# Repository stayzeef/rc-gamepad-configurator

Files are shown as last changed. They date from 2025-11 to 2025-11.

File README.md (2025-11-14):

# RC Gamepad Dongle

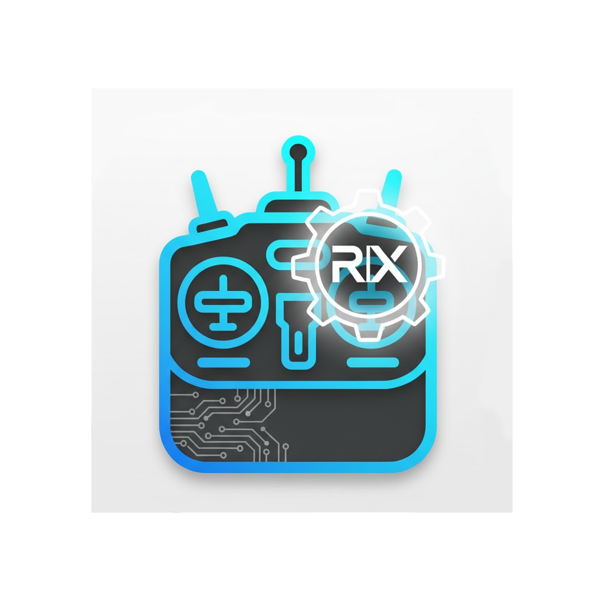
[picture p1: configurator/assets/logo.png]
RC Gamepad Dongle


Turn your RC receiver into a USB game controller. This Arduino-based adapter converts RC signals (IBUS, PPM, SBUS, and more) into standard USB HID joystick inputs that work with Windows, Linux, Mac, Android, and any device that recognizes USB game controllers.

## What Does It Do?

The RC Gamepad Dongle bridges the gap between your RC receiver and your computer. Whether you're using it for flight simulators, robot control, or custom gaming setups, this dongle translates your RC radio signals into joystick inputs that any software can understand.

The project includes Arduino firmware for the dongle itself and a desktop configurator app that makes setup straightforward.

## Key Features

- **Full HID Support**: 6 axes, 32 buttons, and 2 hat switches
- **Multiple RC Protocols**: IBUS, PPM, SBUS, CRSF, DSMX, DSM2, FPORT
- **Easy Configuration**: Map any RC channel to any joystick control
- **Simple Hardware**: Based on the affordable Arduino Pro Micro
- **Cross-Platform**: Works on Windows and Linux

## Hardware You'll Need

### Parts List

- **Arduino Pro Micro** (16MHz/5V version)
- **10kΩ resistor** (for the mode switch)
- **Toggle switch** (to switch between config and joystick modes)
- **WS2812 LED** (optional, gives you visual status feedback)

## Building Your Dongle

You can build this project two ways: you can solder a frankenstein or build a custom PCB

### Option 1: Frankenstein Build
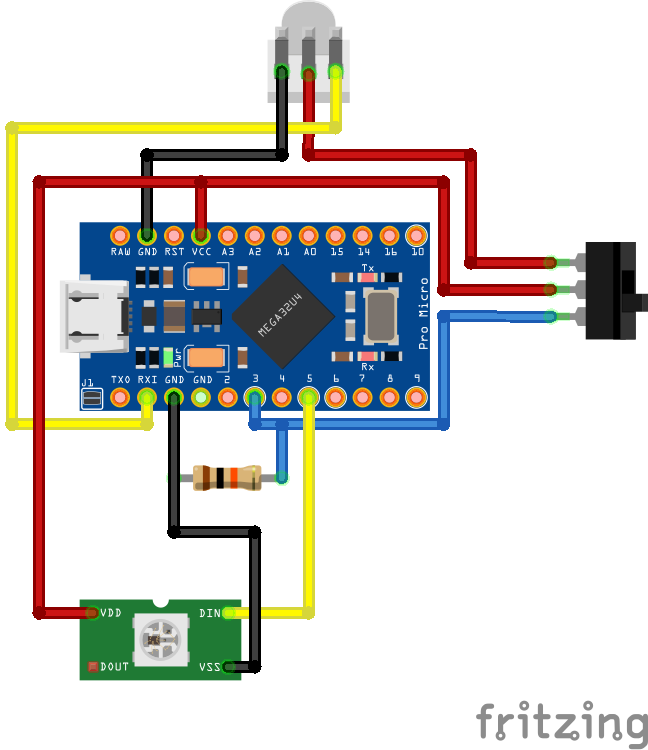
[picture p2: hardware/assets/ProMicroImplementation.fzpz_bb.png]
Breadboard Wiring


**Pin Connections:**
- **Pin 0 (RX)**: Connect your RC receiver signal here
- **Pin 3**: Mode switch (HIGH for config mode, LOW for joystick mode)
    - Connect 10kΩ resistor to ground
- **Pin 5**: Optional WS2812 LED for status indication
- **GND**: Ground connection
- **VCC**: 5V power

### Option 2: Custom PCB

If you want a cleaner build, there's a custom PCB design with all the features built in, including a hardware inverter for SBUS receivers. All the files you need are in `hardware/PCB/`:
- **[Gerber files](hardware/PCB/Gerber_RC-Gamepad-Dongle_V0.1_2025-11-13.zip)**: Ready to send to your PCB manufacturer
- **[Schematic](hardware/PCB/SCH_RC-Gamepad-Dongle%20V0.1_2025-11-13.pdf)**: Full circuit diagram
- **[BOM](hardware/PCB/BOM_RC-Gamepad-Dongle%20V0.1_RC-Gamepad-Dongle%20V0.1_2025-11-13.xlsx)**: Complete parts list with quantities

## Getting Started

### Step 1: Flash the Firmware

First, upload the firmware to your Arduino Pro Micro:

```bash
cd hardware/
pio run --target upload
```

### Step 2: Run the Configurator

**Windows:** Just run the `.exe` file

**Linux:**
```bash
chmod +x RC_Gamepad_Configurator-x86_64.AppImage
./RC_Gamepad_Configurator-x86_64.AppImage
```

**Or run from source:**
```bash
cd configurator
python -m venv .venv
source .venv/bin/activate  # Windows: .venv\Scripts\activate
pip install -r requirements.txt
python src/rc-gamepad-dongle.py
```

### Step 3: Configure Your Channels

1. Flip your mode switch to config mode (pin 3 HIGH)
2. Plug the dongle into your computer via USB
3. Open the configurator app
4. Pick your RC protocol from the dropdown
5. Map your RC channels to the joystick controls you want
6. Click save to write the configuration to the dongle
7. Flip the mode switch back to joystick mode (pin 3 LOW)

That's it! Your dongle is now ready to use as a game controller.

## Supported RC Protocols

| Protocol | Status | Baud Rate | Notes |
|---|---|---|---|
| IBUS | ✅ Tested | 115200 | Works great with FlySky receivers |
| PPM | ✅ Tested | N/A | Standard 8-channel PPM |
| SBUS | ⚠️ Untested | 100000 | Needs hardware inverter (included in PCB) |
| CRSF | ⚠️ Untested | 420000 | TBS Crossfire protocol |
| DSMX | ⚠️ Untested | 115200 | Spektrum DSMX receivers |
| DSM2 | ⚠️ Untested | 115200 | Spektrum DSM2 receivers |
| FPORT | ⚠️ Untested | 115200 | FrSky F.Port protocol |

**Note:** Protocols marked as untested are implemented according to their specifications but haven't been verified with actual hardware yet. If you test one of these, please let us know how it goes!

## Building From Source

### Building the Configurator

**Windows:**
```powershell
.\configurator\scripts\windows\build-exe.ps1
```

**Linux:**
```bash
./configurator/scripts/linux/build-appimage.sh
```

### Building the Firmware

```bash
cd hardware/
pio run                    # Compile the firmware
pio run --target upload    # Upload to your Arduino
pio device monitor         # Monitor serial output
```
## License

This project is released under the MIT License - see [LICENSE](LICENSE) for details.

## Contributing

Want to help improve this project? Pull requests are welcome! I'd especially appreciate help testing the protocols that haven't been verified yet (SBUS, CRSF, DSM, and FPORT). If you have one of these receivers, give it a try and let us know how it works.

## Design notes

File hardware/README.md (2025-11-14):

# RC Gamepad Dongle Firmware

Arduino firmware for the RC Gamepad Configurator project.

## Hardware Assembly

### Breadboard Build
**Components:**
- Arduino Pro Micro (16MHz/5V)
- 10kΩ resistor (pullup for mode switch)
- Toggle switch (mode selection)
- WS2812 LED (optional, status indication)

**Wiring Diagram:**
See `assets/ProMicroImplementation.fzpz_bb.png` for complete Fritzing diagram.

### Custom PCB
**Professional PCB available:**
- Gerber files: `PCB/Gerber_RC-Gamepad-Dongle_V0.1_2025-11-13.zip`
- Schematic: `PCB/SCH_RC-Gamepad-Dongle V0.1_2025-11-13.pdf` 
- BOM: `PCB/BOM_RC-Gamepad-Dongle V0.1_RC-Gamepad-Dongle V0.1_2025-11-13.xlsx`
- Includes hardware SBUS inverter

## Pin Configuration

```
Pin 3  - Mode Select (HIGH=Config, LOW=Joystick)
Pin 5  - WS2812 LED Data (optional)
Pin 0  - RX (RC Receiver Data Input) 
Pin 1  - TX (Not used)
USB    - Configuration & HID output
```

## Quick Start

```bash
cd hardware/
pio run --target upload
```

## Protocol Support

| Protocol | Status | Baud Rate | Testing |
|---|---|---|---|
| IBUS | ✅ Stable | 115200 | ✅ Tested |
| PPM | ✅ Stable | N/A | ✅ Tested |
| CRSF | ⚠️ Implemented | 420000 | ⚠️ Untested |
| SBUS | ⚠️ Implemented | 100000 | ⚠️ Untested |
| DSMX/DSM2| ⚠️ Implemented | 115200 | ⚠️ Untested |
| FPORT | ⚠️ Implemented | 115200 | ⚠️ Untested |

**Note**: Only IBUS and PPM have been tested due to hardware availability.

## Supported Controls

### Joystick Axes
- **X, Y, Z Axes**: Standard 3D movement controls
- **Rx, Ry, Rz Axes**: Rotational controls around X, Y, Z axes

### Specialized Controls  
- **Rudder**: Directional control (typically yaw)
- **Throttle**: Power/speed control
- **Accelerator**: Forward motion control
- **Brake**: Stopping/reverse control  
- **Steering**: Left/right directional control

### Digital Controls
- **32 Buttons**: Individual on/off switches
- **2 Hat Switches**: 8-direction digital controls for menus/navigation

All controls can be mapped to any RC channel (1-16) or disabled.

## Build Requirements

- [PlatformIO](https://platformio.org/)
- Arduino Pro Micro or compatible ATmega32U4 board

## Configuration

Use the GUI configurator application in the parent directory to configure the firmware via serial interface.

## License

MIT License - see main project for details.# Hardware Documentation

## Build Options

### Option 1: Breadboard Build (Beginner-Friendly)

**Required Components:**
- Arduino Pro Micro (16MHz/5V, SparkFun compatible)
- 10kΩ resistor (for mode select pullup)
- Toggle switch (SPDT recommended)
- WS2812 LED (optional, for status indication)
- Breadboard and jumper wires

**Assembly Instructions:**
1. Follow the Fritzing diagram: `hardware/assets/ProMicroImplementation.fzpz_bb.png`
2. Connect the toggle switch to Pin 3 with 10kΩ pullup resistor
3. Connect WS2812 LED data pin to Pin 5 (optional)
4. Connect RC receiver data to Pin 0 (RX)
5. Ensure proper power connections (VCC/GND)

**Wiring Details:**
```
Arduino Pro Micro Connections:
├── Pin 3: Mode Switch + 10kΩ pullup to VCC
├── Pin 5: WS2812 LED Data In (optional)
├── Pin 0: RC Receiver Data (RX)
├── VCC: +5V power
└── GND: Ground reference
```

### Option 2: Custom PCB (Professional)

**PCB Design Files (in `hardware/PCB/`):**
- `Gerber_RC-Gamepad-Dongle_V0.1_2025-11-13.zip` - Manufacturing files
- `SCH_RC-Gamepad-Dongle V0.1_2025-11-13.pdf` - Schematic diagram
- `BOM_RC-Gamepad-Dongle V0.1_RC-Gamepad-Dongle V0.1_2025-11-13.xlsx` - Bill of materials
- `DXF_RC-Gamepad-Dongle V0.1_2025-11-13_AutoCAD2007.dxf` - Mechanical drawings

**PCB Features:**
- Integrated Arduino Pro Micro footprint
- Hardware SBUS signal inverter
- Professional connectors for RC inputs
- Dedicated IBUS and SBUS ports
- Status LED integration
- Compact form factor

**Manufacturing:**
1. Upload Gerber files to PCB manufacturer (JLCPCB, PCBWay, etc.)
2. Use included BOM for component sourcing
3. Assembly can be done manually or with PCBA service

## RC Protocol Connections

### Tested Protocols
| Protocol | Connection | Hardware Notes |
|---|---|---|
| **IBUS** | Pin 0 (RX) direct | Standard 3.3V/5V logic levels |
| **PPM** | Pin 0 (RX) direct | Digital pulse train |

### Implemented Protocols (Untested)
| Protocol | Connection | Hardware Notes |
|---|---|---|
| **SBUS** | PCB SBUS port | Requires hardware inverter (included in PCB) |
| **CRSF** | Pin 0 (RX) direct | 3.3V logic, may need level shifting |
| **DSMX/DSM2** | Pin 0 (RX) direct | Standard logic levels |
| **FPORT** | Pin 0 (RX) direct | Standard logic levels |

⚠️ **Important**: Only connect ONE receiver at a time to prevent conflicts!

## Status LED Indicators

The WS2812 LED provides visual feedback:

| Color | Pattern | Meaning |
|---|---|---|
| **Blue** | Solid | Configuration mode active |
| **Green** | Solid | Joystick mode, receiving data |
| **Dim Green** | Solid | Joystick mode, no data |
| **Red** | Flash | Error condition |
| **Yellow** | Flash | EEPROM write operation |

## Power Requirements

- **Supply Voltage**: 5V via USB or VIN pin
- **Current Draw**: 
  - Base: ~50mA (Arduino + LED)
  - Peak: ~80mA (during USB enumeration)
- **Power Source**: USB port provides sufficient power

## Mechanical Specifications

- **PCB Dimensions**: See DXF file for exact measurements
- **Connector Types**: Standard RC servo connectors
- **Mounting**: Compatible with standard RC electronics mounting

## Troubleshooting

### Hardware Issues
- **No LED**: Check WS2812 wiring and power
- **No USB recognition**: Verify Arduino Pro Micro connections
- **No RC data**: Check receiver binding and connections

### Connection Issues  
- **SBUS not working**: Ensure hardware inverter is present (PCB only)
- **Multiple protocols**: Only connect one receiver type at a time
- **Loose connections**: Use proper connectors or solder joints

## Files Reference

### Fritzing Files (`hardware/assets/`)
- `ProMicroImplementation.fzpz.fzz` - Editable Fritzing project
- `ProMicroImplementation.fzpz_bb.png` - Breadboard view
- `ProMicroImplementation2.fzpz_bb.png` - Alternative view

### PCB Files (`hardware/PCB/`)
- Gerber files for manufacturing
- Complete schematic documentation
- Bill of materials with part numbers
- Mechanical drawings for enclosure design

This hardware documentation supports both beginner breadboard builds and professional PCB implementations.

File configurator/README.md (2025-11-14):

# RC Gamepad Dongle Configurator

Desktop application for configuring the RC Gamepad Dongle. Supports multiple RC protocols including AETR, TAER, and SBUS.

## Features

- Configure RC protocol mappings
- Multiple protocol support (AETR, TAER, SBUS, etc.)
- Serial communication with dongle
- Save/Load configurations
- Cross-platform (Windows & Linux)

## Building

### Windows
```powershell
.\scripts\windows\build-exe.ps1
```
Output: `src\dist\rc-gamepad-dongle.exe`

### Linux
```bash
./scripts/linux/build-appimage.sh
```
Output: `build/RC_Gamepad_Dongle-x86_64.AppImage`

## Development

### Requirements
- Python 3.8+
- PySide6
- PyInstaller
- Pillow

### Install Dependencies
```bash
pip install -r requirements.txt
```

### Run from Source
```bash
cd src
python rc-gamepad-dongle.py
```

## Documentation

See [scripts/README.md](scripts/README.md) for detailed build instructions.

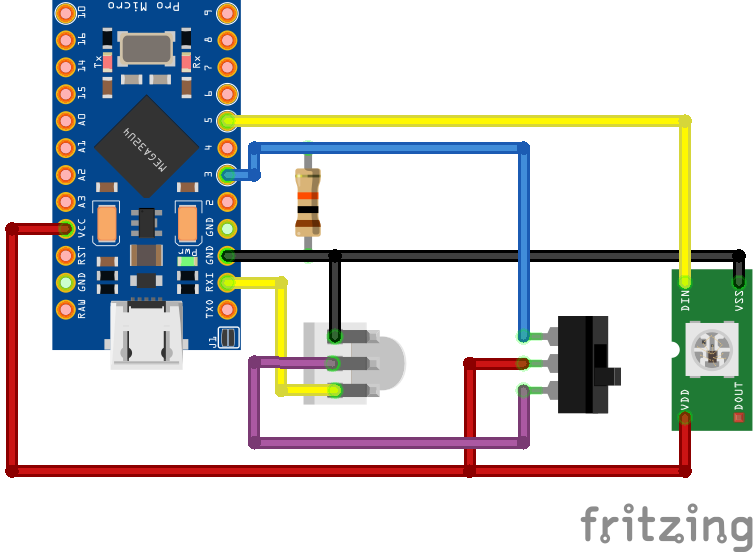
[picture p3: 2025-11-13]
hardware/assets/ProMicroImplementation2.fzpz_bb.png

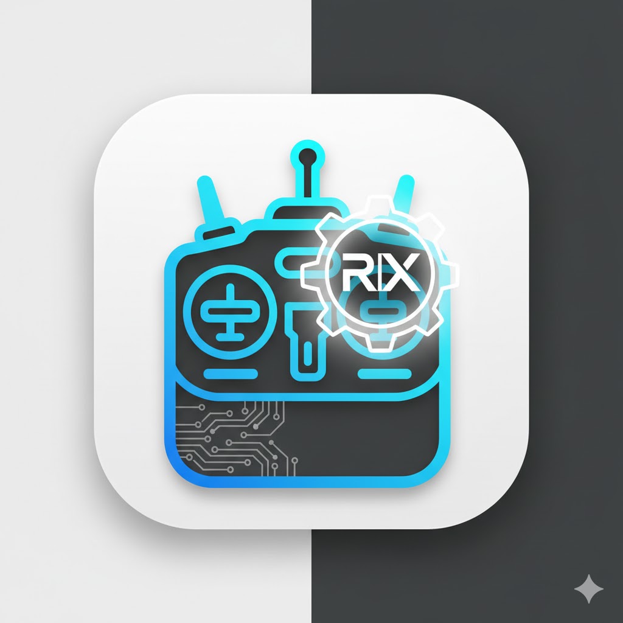
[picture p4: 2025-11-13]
configurator/assets/original.jpg

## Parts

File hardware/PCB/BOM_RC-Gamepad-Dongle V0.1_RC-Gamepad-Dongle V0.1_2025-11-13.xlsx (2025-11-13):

No. | Quantity | Comment | Designator | Footprint | Value | Manufacturer Part | Manufacturer | Supplier Part | Supplier
1 | 2 | 22pF | C1,C2 | C0603 | 22pF | CC0603JRNPO9BN220 | YAGEO(国巨) | C105620 | LCSC
2 | 3 | 100nF | C3,C5,C8 | C0603 | 100nF | CGA0603X7R104K500JT | HRE(芯声) | C6119867 | LCSC
3 | 3 | 1uF | C4,C6,C7 | C0402 | 1uF | CL05A105KP5NNNC | SAMSUNG(三星) | C14445 | LCSC
4 | 1 | SMD0805B050TF | F1 | F0805 |  | SMD0805B050TF | Brightking(君耀电子) | C269104 | LCSC
5 | 2 | SM03B-SRSS-TB(LF)(SN) | iBus,sBus | CONN-SMD_SM03B-SRSS-TB-LF-SN-P |  | SM03B-SRSS-TB(LF)(SN) | JST | C160403 | LCSC
6 | 1 | WS2812B-B/T | Mode | LED-SMD_4P-L5.0-W5.0-TL_WS2812B-B |  | WS2812B-B/T | worldsemi | C2761795 | LCSC
7 | 3 | XL-1608UYC-06 | PWR,RX,TX | LED0603-RD-YELLOW |  | XL-1608UYC-06 | XINGLIGHT(成兴光) | C965802 | LCSC
8 | 1 | 2N7002K-7 | Q1 | SOT-23_L2.9-W1.3-P1.90-LS2.4-BR |  | 2N7002K-7 | DIODES(美台) | C85047 | LCSC
9 | 2 | 22Ω | R1,R2 | R0603 | 22Ω | 0603WAF220JT5E | UNI-ROYAL(厚声) | C23345 | LCSC
10 | 5 | 10kΩ | R3,R6,R7,R8,R9 | R0603 | 10kΩ | FRC0603J103 TS | FOJAN(富捷) | C2930027 | LCSC
11 | 4 | 330Ω | R4,R5,R10,R11 | R0402 | 330Ω | FRC0402J331 TS | FOJAN(富捷) | C2906929 | LCSC
12 | 1 | SK12D07VG5 | SW1 | SW-TH_SK12D07VG5-1 |  | SK12D07VG5 | SHOU HAN(首韩) | C431548 | LCSC
13 | 1 | ATMEGA32U4-AU | U1 | QFP-44_L10.0-W10.0-P0.80-LS13.2-BL |  | ATMEGA32U4-AU | MICROCHIP(美国微芯) | C44854 | LCSC
14 | 1 | AM90 | USB1 | USB-AM-TH_AM90 |  | AM90 | SHOU HAN(首韩) | C404965 | LCSC
15 | 1 | 16MHz | X1 | OSC-SMD_4P-L5.0-W3.2-BL | 16MHz | XVHCELNANF-16MHZ | TAITIEN(泰艺电子) | C242216 | LCSC

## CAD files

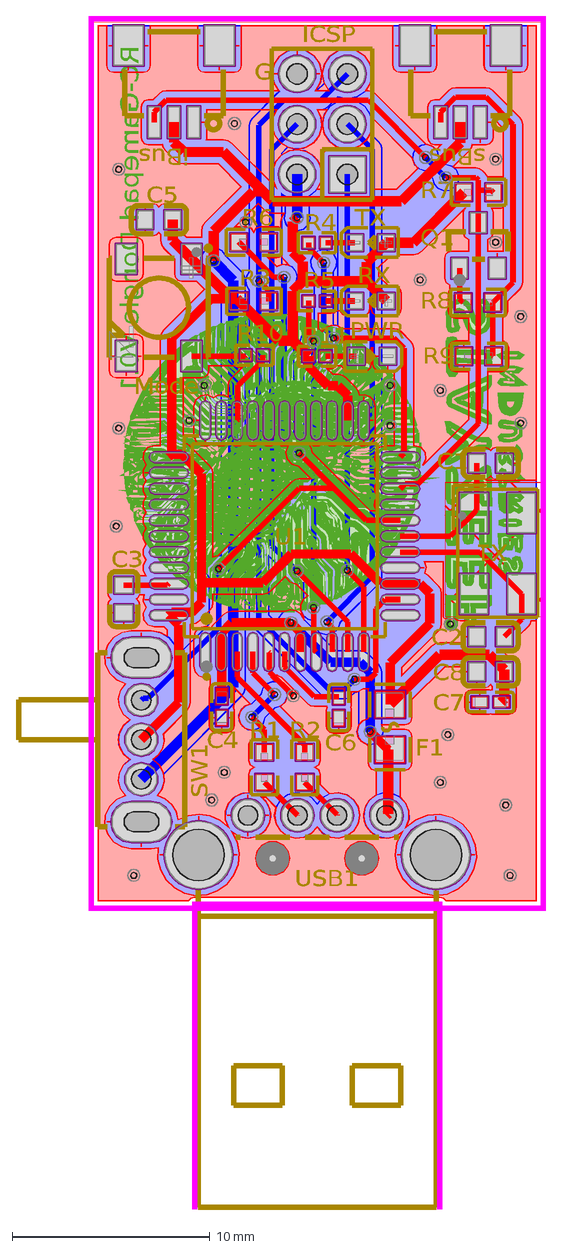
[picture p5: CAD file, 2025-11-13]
hardware/PCB/DXF_RC-Gamepad-Dongle V0.1_2025-11-13_AutoCAD2007.dxf
RC-Gamepad-Dongle V0.1
G
C1
C2
C3
C4
C5
C6
C7
C8
F1
iBus
Mode
PWR
Q1
R1
R2
R3
R4
R5
R6
R7
R8
R9
R10
R11
RX
sBus
SW1
TX
U1
USB1
X1
ICSP

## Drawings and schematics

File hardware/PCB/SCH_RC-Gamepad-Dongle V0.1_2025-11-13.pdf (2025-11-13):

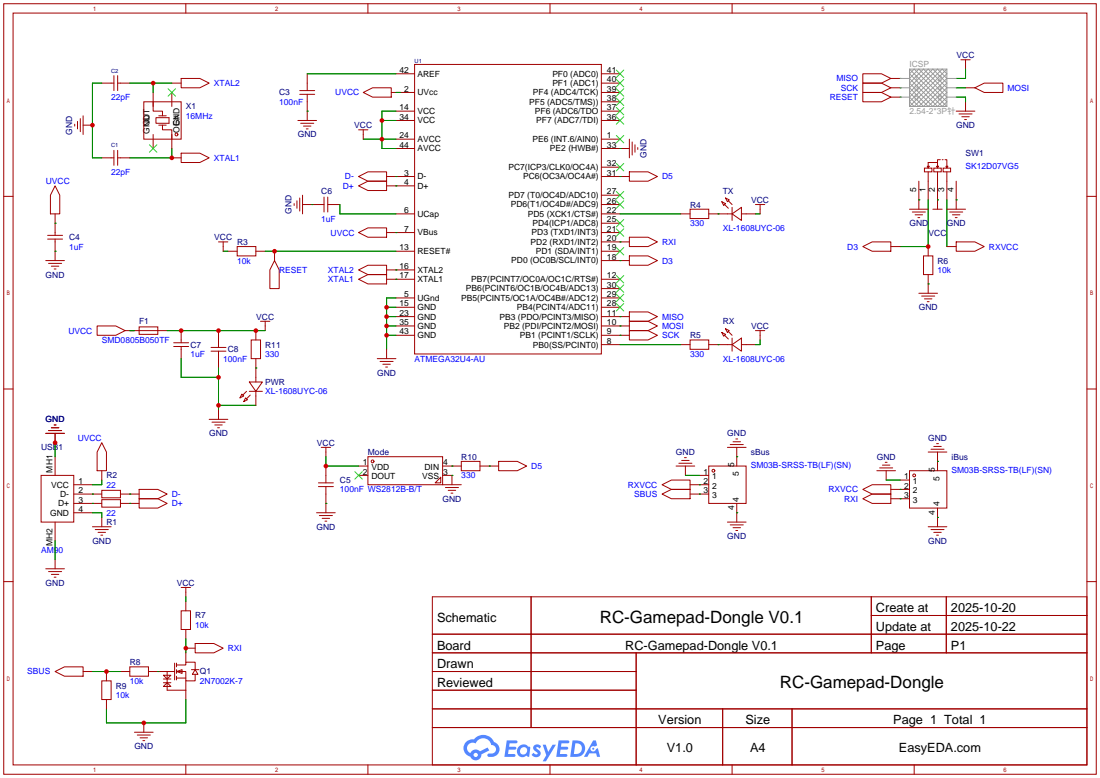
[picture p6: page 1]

PB7(PCINT7/OC0A/OC1C/RTS#) 12
PB2 (PDI/PCINT2/MOSI) 10 PB3 (PDO/PCINT3/MISO) 11 PB4(PCINT4/ADC11) 28 PB5(PCINT5/OC1A/OC4B#/ADC12) 29 PB6(PCINT6/OC1B/OC4B/ADC13) 30

GND
sBus
SM03B-SRSS-TB(LF)(SN)

iBus

Schematic | RC-Gamepad-Dongle V0.1 | Create at | 2025-10-20

Update at | 2025-10-22

Board | RC-Gamepad-Dongle V0.1 | Page | P1
Drawn | | RC-Gamepad-Dongle
Reviewed

Version | Size | Page 1 Total 1
V1.0 | A4 | EasyEDA.com

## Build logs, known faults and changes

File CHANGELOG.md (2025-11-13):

# Changelog

All notable changes to the RC Gamepad Configurator project will be documented in this file.

The format is based on [Keep a Changelog](https://keepachangelog.com/en/1.0.0/),
and this project adheres to [Semantic Versioning](https://semver.org/spec/v2.0.0.html).

## [1.0.0] - 2025-11-13

### Added
- Complete RC-to-USB joystick solution with Arduino firmware and GUI configurator
- Support for multiple RC protocols: IBUS (tested), PPM (tested), CRSF, SBUS, DSMX, DSM2, FPORT
- Modern PySide6 GUI application with dark theme
- Arduino Pro Micro firmware with USB HID joystick emulation
- Real-time configuration via serial interface
- EEPROM configuration storage for persistence
- WS2812 LED status indicators
- Channel conflict prevention in GUI
- JSON configuration file management
- Cross-platform source code (Linux AppImage provided)
- Complete hardware documentation and PCB files

### Testing Status
- ✅ **IBUS Protocol**: Fully tested and stable
- ✅ **PPM Protocol**: Tested and functional, some jitter in the output
- ⚠️ **Other Protocols**: Implemented but untested (no hardware available)

### Note
Only IBUS and PPM protocols have been fully tested due to hardware availability. Other protocols (CRSF, SBUS, DSMX, DSM2, FPORT) are implemented based on specifications but may require testing and refinement.

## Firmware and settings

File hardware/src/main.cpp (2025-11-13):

#include <Arduino.h>
#include <EEPROM.h>
#include <Joystick.h>
#include <IBusBM.h>
#include <Adafruit_NeoPixel.h>
/*
Supported Protocols: IBUS, PPM, CRSF, SBUS, DSMX, DSM2, FPORT

WARNING: Only connect ONE receiver at a time!
- IBUS/CRSF/PPM/DSM2/DSMX/FPORT: Connect to IBUS Port
- SBUS: Connect to SBUS port 
*/

// #define DEBUG  // Enable debug serial output

// Pin definitions
#define MODE_SELECT_PIN 3    // Pin to select mode (HIGH=Config, LOW=Joystick)
#define PPM_PIN 0            // PPM input on RX pin (Pin 0)

// EEPROM addresses
#define EEPROM_SIGNATURE_ADDR    0
#define EEPROM_CONFIG_START_ADDR 8
#define EEPROM_SIGNATURE         0x12345678

#define IBUS 1
#define SBUS 2
#define CRSF 3
#define DSMX 4
#define DSM2 5
#define FPORT 6
#define PPM  7


// WS2812 LED pin
#define WS2812_LED_PIN 5
#define NUM_PIXELS 1

// NeoPixel strip object
Adafruit_NeoPixel strip = Adafruit_NeoPixel(NUM_PIXELS, WS2812_LED_PIN, NEO_GRB + NEO_KHZ800);

// Non-blocking LED state variables
struct LEDState {
  uint8_t r, g, b;
  unsigned long lastUpdate;
  bool active;
  uint8_t mode; // 0=solid, 1=flash, 2=pulse
  uint8_t flashCount;
  uint8_t flashesLeft;
  int pulseDirection; // 1=up, -1=down
  uint8_t pulseBrightness;
} ledState = {0, 0, 0, 0, false, 0, 0, 0, 1, 0};

// Configuration structure
struct JoystickConfig {
  uint8_t protocol;       // Protocol type (e.g., IBusBM)
  uint8_t x_axis;         // Channel for X axis (1-16, 0=disabled)
  uint8_t y_axis;         // Channel for Y axis
  uint8_t z_axis;         // Channel for Z axis
  uint8_t rx_axis;        // Channel for Rx axis (X rotation)
  uint8_t ry_axis;        // Channel for Ry axis (Y rotation)
  uint8_t rz_axis;        // Channel for Rz axis (Z rotation)
  uint8_t rudder;         // Channel for rudder (if applicable)
  uint8_t throttle;       // Channel for throttle (if applicable)
  uint8_t accelerator;    // Channel for accelerator (if applicable)
  uint8_t brake;          // Channel for brake (if applicable)
  uint8_t steering;       // Channel for steering (if applicable)
  uint8_t buttons[32];    // Channels for 32 buttons
  uint8_t hat_switch1;    // Channel for hat switch 1
  uint8_t hat_switch2;    // Channel for hat switch 2
};

// Joystick object - only initialized in joystick mode to save RAM
Joystick_ *joystick = nullptr;

JoystickConfig config;

uint16_t channelData[16] = {1500}; // RC channel data (1000-2000)

bool configMode = false;

// Function prototypes
bool loadConfigFromEEPROM();
bool saveConfigToEEPROM();
void generateDefaultConfig();
void printConfiguration();
bool readIBus();
bool readSBUS();
bool readPPM();
bool readFPORT();
bool readDSM();
void ppmInterrupt();
bool readCRSF();
void updateJoystickFromChannels();
uint16_t mapChannelToAxis(uint16_t channelValue);
bool mapChannelToButton(uint16_t channelValue);
int mapChannelToHat(uint16_t channelValue);
void handleSerialCommands();
void handleSetCommand(String command);
void printConfiguration();
void printHelp();
void reboot();
void generateClearConfig();

// Non-blocking LED utility functions
void setLED(uint8_t r, uint8_t g, uint8_t b);
void startFlashLED(uint8_t r, uint8_t g, uint8_t b, int count = 1);
void startPulseLED(uint8_t r, uint8_t g, uint8_t b);
void updateLED();

// Setup function
void setup() {
  // Initialize NeoPixel
  strip.begin();
  strip.setBrightness(50);
  setLED(0, 0, 0); // Turn off initially

  pinMode(MODE_SELECT_PIN, INPUT);

  configMode = digitalRead(MODE_SELECT_PIN);
  if(configMode) {
    // Configuration Mode
    setLED(0, 0, 255); // Blue for config mode
    delay(100);
    
    // Initialize Serial Communication for Configuration
    Serial.begin(115200);
    while(!Serial); // Wait for Serial to be ready

    // Force serial output even if no connection
    Serial.println("BOOTUP: Serial initialized");
    Serial.flush();
    
    // Load existing configuration
    Serial.println("Loading configuration from EEPROM...");
    if(loadConfigFromEEPROM()) {
      Serial.println("Configuration Loaded Successfully!");
      startFlashLED(0, 255, 0, 2); // Green flash for success
    } else {
      Serial.println("Failed to Load Configuration.");
      startFlashLED(255, 0, 0, 3); // Red flash for error
      Serial.println("Generating default configuration...");
      generateDefaultConfig();
      saveConfigToEEPROM();
      Serial.println("Default configuration generated and saved.");
    }

    Serial.println(F("\n=== RC Gamepad Dongle Configuration ==="));
    Serial.println(F("Firmware OK - 115200 baud"));
    Serial.println(F("Type 'test' to verify"));
    Serial.print(F("Uptime: ")); Serial.println(millis());
    Serial.println(F("Ready..."));
    Serial.flush();
    printConfiguration(); 
    Serial.flush();


  } else {
    #ifdef DEBUG
      Serial.begin(115200);
      while(!Serial); // Wait for Serial to be ready
      Serial.println("BOOTUP: Serial initialized - DEBUG MODE");
      Serial.flush();
    #endif

    // Joystick Mode
    setLED(0, 255, 0); // Green for joystick mode
    delay(100);

    // UNCOMMENT THE NEXT LINE TO CLEAR EEPROM (then comment it out again)
    //EEPROM.put(EEPROM_SIGNATURE_ADDR, (uint32_t)0x00000000);    

    // Load configuration
    if(!loadConfigFromEEPROM()) {
      generateDefaultConfig();
      saveConfigToEEPROM();
    }
 
    // Count assigned buttons
    uint8_t buttonCount = 0;
    for (int i = 0; i < 32; i++) {
      if (config.buttons[i] > 0) {
        buttonCount = i + 1; 
      }
    }

    // Count assigned hat switches
    uint8_t hatCount = 0;
    if (config.hat_switch2 > 0) hatCount = 2;
    else if (config.hat_switch1 > 0) hatCount = 1;    
    
    // Create joystick object with only the controls that are mapped
    joystick = new Joystick_(JOYSTICK_DEFAULT_REPORT_ID, 
                            JOYSTICK_TYPE_JOYSTICK,
                            buttonCount,                     // Only buttons that are assigned
                            hatCount,                        // Only hat switches that are assigned
                            (config.x_axis > 0),             // Include X axis only if mapped
                            (config.y_axis > 0),             // Include Y axis only if mapped
                            (config.z_axis > 0),             // Include Z axis only if mapped
                            (config.rx_axis > 0),            // Include Rx axis only if mapped
                            (config.ry_axis > 0),            // Include Ry axis only if mapped
                            (config.rz_axis > 0),            // Include Rz axis only if mapped
                            (config.rudder > 0),             // Include rudder only if mapped
                            (config.throttle > 0),           // Include throttle only if mapped
                            (config.accelerator > 0),        // Include accelerator only if mapped
                            (config.brake > 0),              // Include brake only if mapped
                            (config.steering > 0)            // Include steering only if mapped
                            );

    #ifdef DEBUG
      Serial.println("Joystick object created.");
      Serial.print("USB Status - USBCON: 0x"); Serial.println(USBCON, HEX);
      Serial.print("UDCON: 0x"); Serial.println(UDCON, HEX);
      Serial.flush();
    #endif                            

    if (joystick) {
      joystick->begin();
      
      // Allow time for USB HID enumeration
      delay(500);
      
      // Only set ranges for axes that are actually mapped
      if (config.x_axis > 0) joystick->setXAxisRange(0, 1023);
      if (config.y_axis > 0) joystick->setYAxisRange(0, 1023);
      if (config.z_axis > 0) joystick->setZAxisRange(0, 1023);
      if (config.rx_axis > 0) joystick->setRxAxisRange(0, 1023);
      if (config.ry_axis > 0) joystick->setRyAxisRange(0, 1023);
      if (config.rz_axis > 0) joystick->setRzAxisRange(0, 1023);
      if(config.rudder > 0) joystick->setRudderRange(0, 1023);
      if(config.throttle > 0) joystick->setThrottleRange(0, 1023);
      if(config.accelerator > 0) joystick->setAcceleratorRange(0, 1023);
      if(config.brake > 0) joystick->setBrakeRange(0, 1023);
      if(config.steering > 0) joystick->setSteeringRange(0, 1023);

      // flashLED(0, 255, 0, 2); // Green flash for success

      #ifdef DEBUG
      Serial.println(F("Joystick init OK"));
      Serial.print(F("Buttons: ")); Serial.print(buttonCount);
      Serial.print(F(", Hats: ")); Serial.print(hatCount);
      Serial.print(F(", Axes: "));
      if (config.x_axis > 0) Serial.print(F("X "));
      if (config.y_axis > 0) Serial.print(F("Y "));
      if (config.z_axis > 0) Serial.print(F("Z "));
      if (config.rx_axis > 0) Serial.print(F("RX "));
      if (config.ry_axis > 0) Serial.print(F("RY "));
      if (config.rz_axis > 0) Serial.print(F("RZ "));
      if (config.rudder > 0) Serial.print(F("Rudder "));
      if (config.throttle > 0) Serial.print(F("Throttle "));
      if (config.accelerator > 0) Serial.print(F("Accelerator "));
      if (config.brake > 0) Serial.print(F("Brake "));
      if (config.steering > 0) Serial.print(F("Steering "));
      Serial.println();
      #endif
    } else {
      // flashLED(255, 0, 0, 3); // Red flash for error
      reboot();
      #ifdef DEBUG
      Serial.println(F("ERROR: Joystick failed"));
      #endif
    }
  }
}

void loop() {
  if (configMode) {
    // Configuration mode - handle serial commands
    handleSerialCommands();
    updateLED(); // Update non-blocking LED effects
    
    // Check for mode switch
    // if(digitalRead(MODE_SELECT_PIN) == LOW) {
    //   // Exit config mode if pin goes LOW
    //   Serial.println(F("Exiting configuration mode, rebooting..."));
    //   delay(1000);
    //   reboot();
    // }
    
  } else {
    // Joystick mode - handle RC receiver and joystick updates
    updateLED(); // Update non-blocking LED effects
    bool validData = false;
    
    // Read data based on configured protocol
    switch (config.protocol) {
      case IBUS:
        validData = readIBus();
        break;
      case SBUS:
        validData = readSBUS();
        break;
      case CRSF:
        validData = readCRSF();
        break;
      case DSMX:
        validData = readDSM();
        break;
      case DSM2:
        validData = readDSM();
        break;
      case FPORT:
        validData = readFPORT();
        break;
      case PPM:
        validData = readPPM();
        break;
      default:
        validData = readIBus(); // Fallback to IBUS
        break;
    }
    
    if (validData && joystick) {
      updateJoystickFromChannels();
      // Quick green pulse for data received
      static unsigned long lastFlash = 0;
      if (millis() - lastFlash > 500) {
        setLED(0, 255, 0); // Bright green for data
        lastFlash = millis();
      }
    } else {
      // No data - dim green
      setLED(0, 64, 0); // Dim green for no data
    }

    // Reboot if mode select pin changes
    // if(digitalRead(MODE_SELECT_PIN) == HIGH) {
    //   reboot();
    // }       
  }
}

bool readIBus() {
  static IBusBM ibus; // Create static instance only when needed
  static bool initialized = false;
  
  if (!initialized) {
    Serial1.begin(115200);
    ibus.begin(Serial1);
    initialized = true;
  }
  
  ibus.loop();
  if (ibus.cnt_rec > 0) {
    // Read channel data
    for (int i = 0; i < 16 && i < ibus.cnt_rec; i++) {
      channelData[i] = ibus.readChannel(i);
    }
    #ifdef DEBUG
      Serial.print("IBus Channels: ");
      for (int i = 0; i < 3; i++) {
        Serial.print(channelData[i]);
        Serial.print(" ");
      }
      Serial.println();
    #endif

    return true;
  }
  return false;
}

// PPM state structure - only allocated when PPM protocol is used
struct PPMState {
  volatile unsigned long pulseStartTime;
  volatile uint16_t channelValues[16];
  volatile uint16_t filteredChannels[16];  // Filtered channel values
  volatile uint8_t channelCount;
  volatile bool frameComplete;
  volatile uint8_t currentChannel;
  volatile unsigned long lastValidFrame;   // Timestamp of last valid frame
  volatile uint8_t missedFrames;          // Count of missed/invalid frames
};

// Global pointer to PPM state - only allocated when needed
PPMState* ppmState = nullptr;

// PPM interrupt service routine
void ppmInterrupt() {
  if (!ppmState) return; // Safety check
  
  const uint16_t PPM_MIN_PULSE_WIDTH = 900;   // Tighter range
  const uint16_t PPM_MAX_PULSE_WIDTH = 2100;
  const uint16_t PPM_SYNC_GAP = 3000;         // Lower sync gap threshold
  const uint16_t PPM_MAX_SYNC_GAP = 25000;    // Maximum reasonable sync gap
  
  unsigned long currentTime = micros();
  unsigned long pulseWidth = currentTime - ppmState->pulseStartTime;
  ppmState->pulseStartTime = currentTime;
  
  // Ignore very short or very long pulses (noise rejection)
  if (pulseWidth < 500 || pulseWidth > PPM_MAX_SYNC_GAP) {
    return;
  }
  
  if (pulseWidth > PPM_SYNC_GAP) {
    // Sync pulse detected - validate and start new frame
    if (ppmState->currentChannel >= 4 && ppmState->currentChannel <= 16) {
      // Valid frame completed
      ppmState->channelCount = ppmState->currentChannel;
      ppmState->frameComplete = true;
      ppmState->lastValidFrame = currentTime;
      ppmState->missedFrames = 0;
    } else {
      // Invalid frame
      ppmState->missedFrames++;
    }
    ppmState->currentChannel = 0;
  } else if (pulseWidth >= PPM_MIN_PULSE_WIDTH && pulseWidth <= PPM_MAX_PULSE_WIDTH) {
    // Valid channel pulse - store directly for maximum responsiveness
    if (ppmState->currentChannel < 16) {
      ppmState->channelValues[ppmState->currentChannel] = pulseWidth;
      ppmState->currentChannel++;
    }
  }
  // Ignore pulses outside valid range (noise rejection)
}

bool readPPM() {
  static bool initialized = false;
  static unsigned long lastDataTime = 0;
  
  if (!initialized) {
    // Allocate PPM state only when needed
    ppmState = new PPMState();
    ppmState->pulseStartTime = 0;
    ppmState->channelCount = 0;
    ppmState->frameComplete = false;
    ppmState->currentChannel = 0;
    ppmState->lastValidFrame = 0;
    ppmState->missedFrames = 0;
    
    // Initialize with center values
    for (int i = 0; i < 16; i++) {
      ppmState->channelValues[i] = 1500;
    }
    
    pinMode(PPM_PIN, INPUT);
    attachInterrupt(digitalPinToInterrupt(PPM_PIN), ppmInterrupt, RISING);
    initialized = true;
    lastDataTime = millis();
    
    #ifdef DEBUG
      Serial.println("PPM interrupt attached to pin 0");
    #endif
  }
  
  // Check for signal timeout (no data for 100ms)
  unsigned long currentTime = millis();
  if (currentTime - lastDataTime > 100) {
    return false; // No recent data
  }
  
  if (ppmState && ppmState->frameComplete && ppmState->channelCount >= 4) {
    // Check if too many frames were missed (signal quality check)
    if (ppmState->missedFrames > 20) { // More lenient threshold
      #ifdef DEBUG
        Serial.println("PPM: Too many missed frames, signal unstable");
      #endif
      return false;
    }
    
    // Copy data directly for maximum responsiveness
    noInterrupts();
    for (int i = 0; i < ppmState->channelCount && i < 16; i++) {
      channelData[i] = ppmState->channelValues[i];
    }
    ppmState->frameComplete = false;
    lastDataTime = currentTime;
    interrupts();
    
    #ifdef DEBUG
      static unsigned long lastDebugTime = 0;
      if (currentTime - lastDebugTime > 1000) { // Debug every second
        Serial.print("PPM Channels (");
        Serial.print(ppmState->channelCount);
        Serial.print(", missed: ");
        Serial.print(ppmState->missedFrames);
        Serial.print("): ");
        for (int i = 0; i < min(3, (int)ppmState->channelCount); i++) {
          Serial.print(channelData[i]);
          Serial.print(" ");
        }
        Serial.println();
        lastDebugTime = currentTime;
      }
    #endif
    
    return true;
  }
  
  return false;
}

// CRSF protocol implementation
// CRSF frame format: SYNC(0xC8) + LENGTH + TYPE + PAYLOAD + CRC
// RC Channels payload: 16 channels, 11-bit each, packed into 22 bytes
bool readCRSF() {
  static bool initialized = false;
  static uint8_t frameBuffer[64];  // Buffer for incoming frame
  static uint8_t frameIndex = 0;
  static uint8_t expectedLength = 0;
  static unsigned long lastValidFrame = 0;
  static unsigned long lastByteTime = 0;
  
  const uint8_t CRSF_SYNC_BYTE = 0xC8;
  const uint8_t CRSF_FRAME_RC_CHANNELS = 0x16;
  const uint8_t CRSF_RC_CHANNELS_PAYLOAD_SIZE = 22;
  const unsigned long CRSF_TIMEOUT_MS = 100;
  const unsigned long CRSF_BYTE_TIMEOUT_MS = 10;
  
  if (!initialized) {
    Serial1.begin(420000); // CRSF standard baud rate
    initialized = true;
    lastValidFrame = millis();
    frameIndex = 0;
    
    #ifdef DEBUG
      Serial.println("CRSF initialized at 420000 baud");
    #endif
  }
  
  unsigned long currentTime = millis();
  
  // Reset frame if timeout between bytes
  if (frameIndex > 0 && (currentTime - lastByteTime) > CRSF_BYTE_TIMEOUT_MS) {
    frameIndex = 0;
    expectedLength = 0;
    #ifdef DEBUG
      Serial.println("CRSF: Byte timeout, resetting frame");
    #endif
  }
  
  // Process incoming bytes
  while (Serial1.available() && frameIndex < sizeof(frameBuffer)) {
    uint8_t byte = Serial1.read();
    lastByteTime = currentTime;
    
    if (frameIndex == 0) {
      // Look for sync byte
      if (byte == CRSF_SYNC_BYTE) {
        frameBuffer[frameIndex++] = byte;
      }
    } else if (frameIndex == 1) {
      // Frame length byte
      if (byte >= 3 && byte <= 62) { // Valid CRSF frame length range
        frameBuffer[frameIndex++] = byte;
        expectedLength = byte + 2; // +2 for sync and length bytes
      } else {
        frameIndex = 0; // Invalid length, reset
      }
    } else {
      // Collect frame data
      frameBuffer[frameIndex++] = byte;
      
      // Check if frame is complete
      if (frameIndex >= expectedLength) {
        // Verify frame type for RC channels
        if (frameBuffer[2] == CRSF_FRAME_RC_CHANNELS && 
            frameBuffer[1] == (CRSF_RC_CHANNELS_PAYLOAD_SIZE + 2)) { // +2 for type and CRC
          
          // Simple CRC check (XOR of all bytes except sync and CRC)
          uint8_t calculatedCRC = 0;
          for (int i = 1; i < expectedLength - 1; i++) {
            calculatedCRC ^= frameBuffer[i];
          }
          
          if (calculatedCRC == frameBuffer[expectedLength - 1]) {
            // Valid frame, extract channel data
            uint8_t *payload = &frameBuffer[3]; // Skip sync, length, type
            
            // Unpack 16 channels from 22 bytes (11-bit channels)
            uint16_t channels[16];
            uint32_t bitBuffer = 0;
            uint8_t bitCount = 0;
            uint8_t channelIndex = 0;
            
            for (int i = 0; i < CRSF_RC_CHANNELS_PAYLOAD_SIZE && channelIndex < 16; i++) {
              bitBuffer |= ((uint32_t)payload[i]) << bitCount;
              bitCount += 8;
              
              while (bitCount >= 11 && channelIndex < 16) {
                channels[channelIndex] = bitBuffer & 0x7FF; // Extract 11 bits
                bitBuffer >>= 11;
                bitCount -= 11;
                channelIndex++;
              }
            }
            
            // Convert CRSF channel range (172-1811) to standard RC range (1000-2000)
            for (int i = 0; i < 16; i++) {
              if (channels[i] < 172) channels[i] = 172;
              if (channels[i] > 1811) channels[i] = 1811;
              channelData[i] = map(channels[i], 172, 1811, 1000, 2000);
            }
            
            lastValidFrame = currentTime;
            frameIndex = 0;
            expectedLength = 0;
            
            #ifdef DEBUG
              static unsigned long lastDebugTime = 0;
              if (currentTime - lastDebugTime > 1000) { // Debug every second
                Serial.print("CRSF Channels: ");
                for (int i = 0; i < 3; i++) {
                  Serial.print(channelData[i]);
                  Serial.print(" ");
                }
                Serial.println();
                lastDebugTime = currentTime;
              }
            #endif
            
            return true;
          } else {
            #ifdef DEBUG
              Serial.println("CRSF: CRC mismatch");
            #endif
          }
        }
        
        // Reset for next frame
        frameIndex = 0;
        expectedLength = 0;
      }
    }
  }
  
  // Check for overall timeout
  if (currentTime - lastValidFrame > CRSF_TIMEOUT_MS) {
    return false;
  }
  
  return false; // No complete frame received this cycle
}
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

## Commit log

2025-11-13 feat: initial release of RC Gamepad Configurator v1.0.0
    Complete RC-to-USB joystick solution with:
    - Modern PySide6 GUI configurator
    - Arduino Pro Micro firmware
    - Support for 7 RC protocols (IBUS/PPM tested)
    - USB HID joystick emulation
    - Real-time configuration via serial
    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
    [BOM_RC-Gamepad-Dongle V0.1_RC-Gamepad-Dongle V0.1_2025-11-13.xlsx, DXF_RC-Gamepad-Dongle V0.1_2025-11-13_AutoCAD2007.dxf, ProMicroImplementation.fzpz.fzz]
2025-11-13 Update PCB design tool from KiCad to EasyEDA
2025-11-14 Project Clean Up
    [BOM_RC-Gamepad-Dongle V0.1_RC-Gamepad-Dongle V0.1_2025-11-13.xlsx, DXF_RC-Gamepad-Dongle V0.1_2025-11-13_AutoCAD2007.dxf, ProMicroImplementation.fzpz.fzz]
2025-11-14 Add PCB schematic image
